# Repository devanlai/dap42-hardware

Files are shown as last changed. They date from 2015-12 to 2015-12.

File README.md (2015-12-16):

# dap42-hardware
Hardware design files for the dap42 debug probe.

Bare PCBs can be ordered from [OSHPark](https://oshpark.com/shared_projects/DoRvlUH0)

See https://github.com/devanlai/dap42 for firmware source code.

Both original DipTrace CAD files and gerber production files are included. For convenience, a PDF of the schematic and PNG renders of the top and bottom side of the board are included.

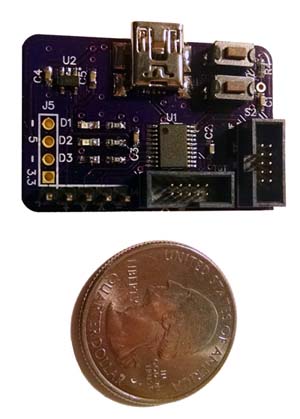
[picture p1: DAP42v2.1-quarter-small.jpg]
Assembled DAP42v2.1 with quarter for scale


# Parts
* 1x STM32F042F6 (TSSOP-20)
* 2x 0.05" 2x5 SWD headers, one for debugging the target, one for debugging the probe (optional)
* 1x mini-USB type B connector
* 1x 5V -> 3.3V linear regulator (MIC5504-3.3YM5)
* 2x 3mm momentary pushbuttons for reset and bootloader (optional)
* 3x LEDs (optional, but fun to look at)

See the [bill of materials](BOM.md) for a more detailed list.

# License


To the extent possible under law, Devan Lai has waived all copyright and related or neighboring rights to the dap42 schematic, PCB layout, and associated CAD and gerber production files. This work is published from: United States.

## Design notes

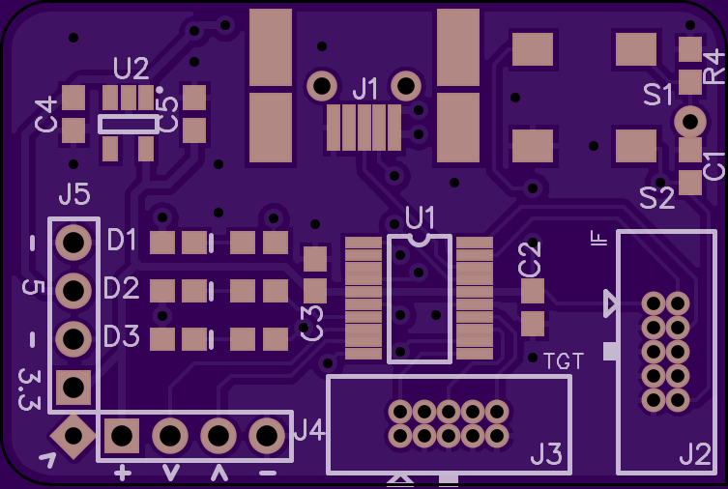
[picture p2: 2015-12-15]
render-top-v2.png

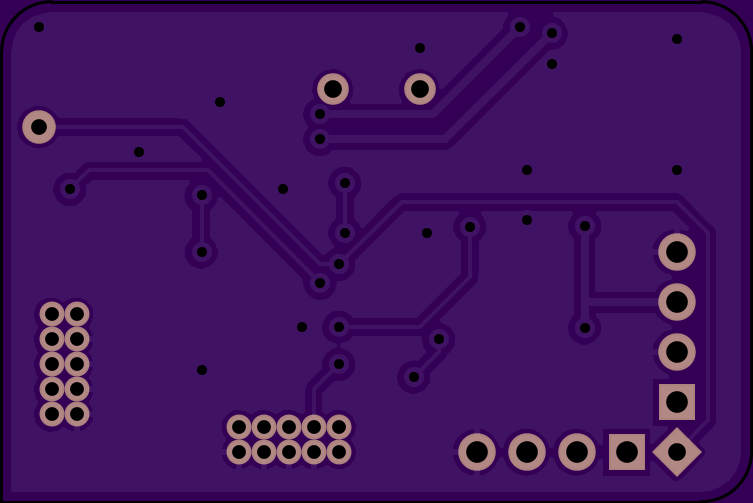
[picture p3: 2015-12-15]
render-bottom-v2.png

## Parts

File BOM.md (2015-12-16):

# Bill of Materials for dap42 revision 2 (dap42v2)
Unless otherwise specified, all resistors, capacitors, and LEDs are in 0603 packages.

Unspecified part numbers are either generic with (virtually) no design constraints, or were not sourced from a distributor with an offical part number.

RefDes | P/N | Notes
---|------------------------|------------
U1 | STM32F042F6            | STM32F042F6
U2 | MIC5504-3.3YM5         | 5V -> 3.3V LDO, SOT-23-5
S1 | ADTSM31NV              | Momentary pushbutton, bootloader enable
S2 | ADTSM31NV              | Momentary pushbutton, reset
J1 | | Mini-USB type B connector
J2 | GoPortHeader_th_10pack<sup>[1](#f1)</sup> | 0.05" pitch, 2x5 shrouded male socket, SWD debug header for the dap42
J3 | GoPortHeader_th_10pack<sup>[1](#f1)</sup> | 0.05" pitch, 2x5 shrouded male socket, SWD debug header for the target
J4 | | 0.1" pitch, 4-pin header for external UART
J5 | | 0.1" pitch, 4-pin header for 3.3V and 5V power and ground
D1 | | LED, LED0/Connected
D2 | | LED, LED1/Running
D3 | | LED, LED2/USB activity
R1 | | 1kOhm
R2 | | 1kOhm
R3 | | 1kOhm
R4 | | 10kOhm
C1 | | 0.1uF
C2 | | 0.1uF
C3 | | 0.1uF
C4 | | 1uF
C5 | | 1uF

---
<sup id="f1">1. P/N is for a 10-pack of shrouded headers, can also substitute unshrouded male headers</sup>

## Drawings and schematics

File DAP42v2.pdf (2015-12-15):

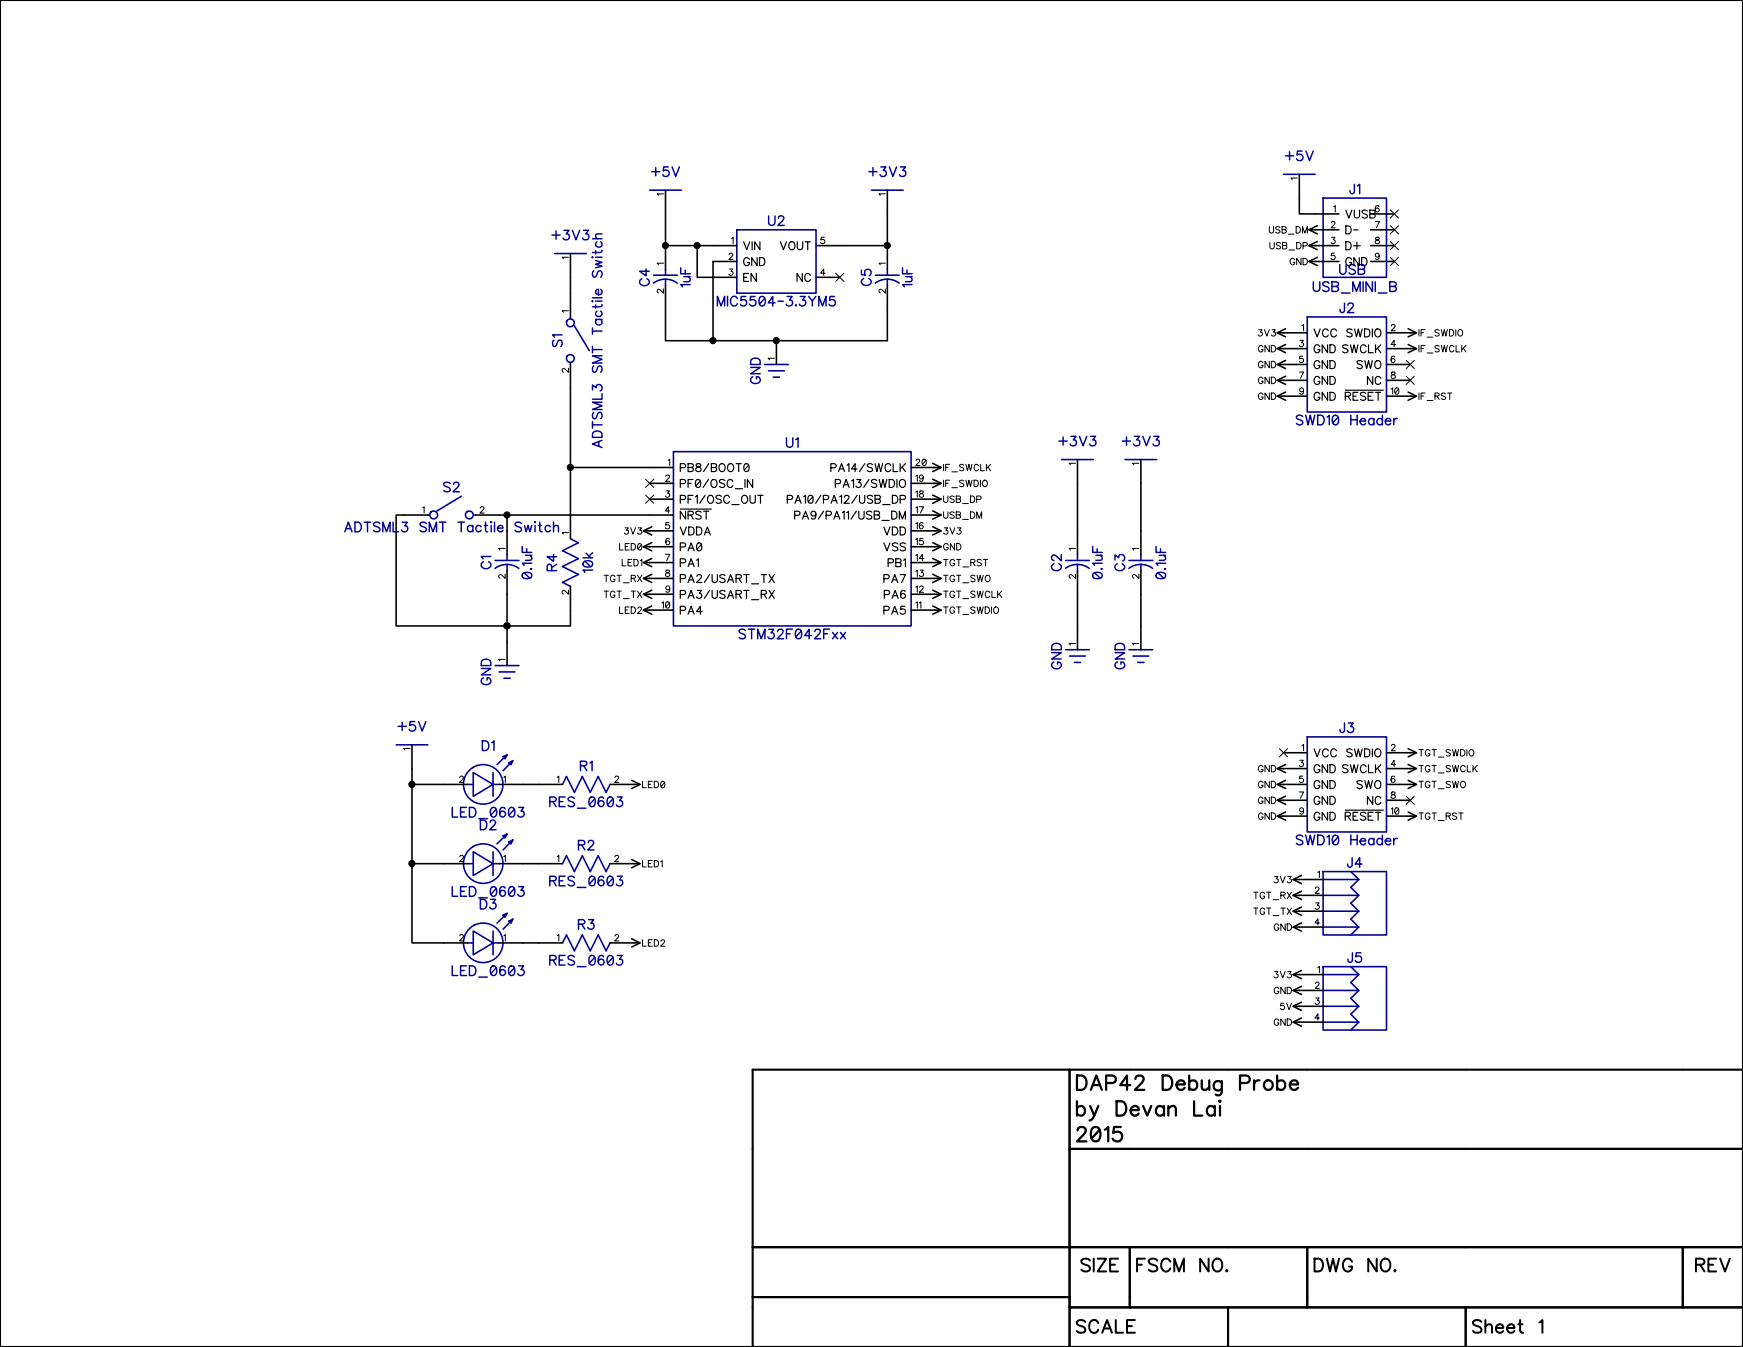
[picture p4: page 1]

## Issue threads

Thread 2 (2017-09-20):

Feature request: full JTAG support

xcvista, 2017-09-20:
There are some scenarios where it is necessary to us the full JTAG interface instead of the SWD interface to connect the DAP to the DUT, for example a JTAG daisy chain, a Cortex-A target like the Raspberry Pi, or when the older ARM7/ARM9/ARM11 chips gets involved. Is it possible to implement full JTAG on top of the current hardware and software?

JTAG uses a few existing SWD pins along with a few more:

* JTMS / SWDIO (Existing pin, bidirectional in SWD, output in JTAG, with pull up)
* JTCK / SWCLK (Existing pin, output with pull down)
* JTDI (new pin, output with pull up)
* JTDO / SWO (Existing pin, input with pull up)
* nJTRST (new pin, output with pull up)
* RTCK (new pin, input with pull down)

The RTCK pin worths some special mentioning: it is used on ARM7/ARM9/ARM11/Cortex-A chips to implement adaptive JTAG clocking. However this feature is entirely optional. You can just pull this pin down with a resistor and ignore it otherwise, if you have no plan on implementing JTAG adaptive clocking. There do exist some chips (like NXP LPC2103) that uses the pull down on RTCK to detect the presence of a debugger though.

devanlai, 2017-09-20:
It's theoretically possible, though I'm not sure that the JTAG throughput will be satisfactory - the CMSIS-DAP commands for JTAG are very close to just passing bit-banging commands over USB HID, so the best-case performance would look similar to using a different adapter with a JTAG clock rate of 256KHz.

If you want to try it out yourself, here are the steps to do it:
On the hardware side, there are two unused pins (PF0 and PF1) which you can use for JTDI and nJTRST.
For RTCK, if you wanted to do adaptive clocking, it would be necessary to multiplex or repurpose one of the existing pins. Some possible candidates:

- PA13/PA14 - if you're not interested in debugging the debugger, you could use the debugger's SWDIO or SWCLK pin for RTCK.
- PB8 - if you set the option byte to disable the BOOT0 function, then you can use PB8 for anything.
- PA0/PA1/PA4 - you could drop one of the LEDs

In software, the source still includes a copy of the reference CMSIS-DAP JTAG bit-banging code, so enabling it is really just a matter of changing some defines and hooking up the relevant JTAG pin definitions.

xcvista, 2017-09-21:
I think that PB8 can be used for RTCK without dealing with the option bytes, since it is pulled down by default as BOOT0 should be when powered up.

devanlai, 2017-09-21:
That seems reasonable, since RTCK should only ever be a delayed copy of JTCK.

xcvista, 2017-10-28:
I am in the process of building one based on this hardware idea, although some changes are made:

* RTCK not connected to the microcontroller,
* SWO support omitted (freeing up resources for

ildar, 2019-11-18:
@xcvista , did you build a working prototype? (HW + FW)
what's your target chip? (I'm still looking for JTAG FW for my BluePill)

xcvista, 2019-11-20:
@ildar I have several versions of hardware but I have little time for the software now.

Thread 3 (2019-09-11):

STM32F103 pinout

ildar, 2019-09-11:
https://github.com/devanlai/dap42 supports STM32F103 but no hardware design or just a mere pinout is available.

ildar, 2019-09-11:
meanwhile https://github.com/devanlai/dap42/blob/master/src/stm32f103/stlinkv2-dongle/DAP/CMSIS_DAP_config.h#L129

devanlai, 2019-09-11:
Hi @ildar, I don't have a hardware design for the STM32F103 because the F103 variant of the firmware targets ST-Link/v2 clone hardware, which is mind-bogglingly affordable.

You can either refer to various reverse-engineered schematics of the clone hardware, or to a subset of the official ST-Link/v2 schematic, depending on your preference. As you've already found, the relevant pinout for my firmware on the STM32F103 is in the header files, which I've reproduced here:

| Name | Pin |
| --- | --- |
| SWCLK | PB13 |
| SWDIO | PB14 |
| UART RX / SWO |  PB11 |
| RST | PB6 |
| LED | PA9 |

ildar, 2019-09-11:
Yes, thanks a lot! It runs on a BluePill perfectly!

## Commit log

2015-12-15 Initial import
    [Board.gbr, BoardOutline.gbr, Bottom.gbr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]
2015-12-16 Add bill of materials for revision 2
2015-12-16 Add link to BOM in README.md
2015-12-16 Add photo of assembled DAP42v2.1
2016-01-09 Add docker-based schematic-to-png renderer script
2016-10-23 Add python implementation of render-schematic
    Add python implementation that does everything in memory instead of
    using temporary files.
    Change CircleCI setup to render all .dch files

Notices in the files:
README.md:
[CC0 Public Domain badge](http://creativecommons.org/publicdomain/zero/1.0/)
